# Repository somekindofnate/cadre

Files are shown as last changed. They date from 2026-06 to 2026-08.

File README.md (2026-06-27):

```
 ░▒▓██████▓▒░ ░▒▓██████▓▒░░▒▓███████▓▒░░▒▓███████▓▒░░▒▓████████▓▒░ 
░▒▓█▓▒░░▒▓█▓▒░▒▓█▓▒░░▒▓█▓▒░▒▓█▓▒░░▒▓█▓▒░▒▓█▓▒░░▒▓█▓▒░▒▓█▓▒░        
░▒▓█▓▒░      ░▒▓█▓▒░░▒▓█▓▒░▒▓█▓▒░░▒▓█▓▒░▒▓█▓▒░░▒▓█▓▒░▒▓█▓▒░        
░▒▓█▓▒░      ░▒▓████████▓▒░▒▓█▓▒░░▒▓█▓▒░▒▓███████▓▒░░▒▓██████▓▒░   
░▒▓█▓▒░      ░▒▓█▓▒░░▒▓█▓▒░▒▓█▓▒░░▒▓█▓▒░▒▓█▓▒░░▒▓█▓▒░▒▓█▓▒░        
░▒▓█▓▒░░▒▓█▓▒░▒▓█▓▒░░▒▓█▓▒░▒▓█▓▒░░▒▓█▓▒░▒▓█▓▒░░▒▓█▓▒░▒▓█▓▒░        
 ░▒▓██████▓▒░░▒▓█▓▒░░▒▓█▓▒░▒▓███████▓▒░░▒▓█▓▒░░▒▓█▓▒░▒▓████████▓▒░ 

Civilian-Available Drone REcon
```

### Disclaimer
The following program is intended for research purposes **only**. The situations described are fictional in nature and only used as examples. As the MIT license states:

> THE SOFTWARE IS PROVIDED “AS IS”, WITHOUT WARRANTY OF ANY KIND, EXPRESS OR IMPLIED, INCLUDING BUT NOT LIMITED TO THE WARRANTIES OF MERCHANTABILITY, FITNESS FOR A PARTICULAR PURPOSE AND NONINFRINGEMENT. IN NO EVENT SHALL THE AUTHORS OR COPYRIGHT HOLDERS BE LIABLE FOR ANY CLAIM, DAMAGES OR OTHER LIABILITY, WHETHER IN AN ACTION OF CONTRACT, TORT OR OTHERWISE, ARISING FROM, OUT OF OR IN CONNECTION WITH THE SOFTWARE OR THE USE OR OTHER DEALINGS IN THE SOFTWARE.

**Using this software in an unlicensed, unauthorized way can put you in prison. Don't do it.**

# Rationale
As of 2026, ongoing conflicts have showed that when the lack of military hardware is available, state and nonstate actors will turn to civilian, off-the-shelf (COTS) hardware. The Myanmar Civil War \[1\], Russo-Ukrainian conflict, and -- to a lesser degree -- Syrian Civil War \[3\] and outspringing conflicts have all used commercially available drones for mission-built purposes.

Because necessity is the mother of invention, both military-industrial grade and battlefield made countermeasures have been used successfully to stop drones. [The Ukranian Chuyka](https://www.blue-bird.tech/en/products/chuyka-3-0/) is a valuable piece of tech for front line troops, allowing them to eavesdrop on unecrypted, analog video of loitering drones. However, it's a piece of tech that's almost $2,000 here in the United States. There are other drone detection hardware devices of varying quality [littered across eBay](https://www.ebay.com/itm/376574536302). Inspired by Colonel Panic's [Drone Mesh Mapper](https://github.com/colonelpanichacks/drone-mesh-mapper) and [DroneAware.io](https://droneaware.io/), this project is an exploration of what technologies could be used in a cheap, open, and commercially-available way to detect a hypothetical drone incursion.

The scope of this research is limited to the 2.4GHZ and 5.8GHZ bands that some commercially-available drones use for controls, phone-home, or analog/digital video signals. This is not intended for fiber optic, special-frequency, industrial, or other drone types. There is no warranty provided and the authors of this project shall not be held liable for any part in the use of this project.

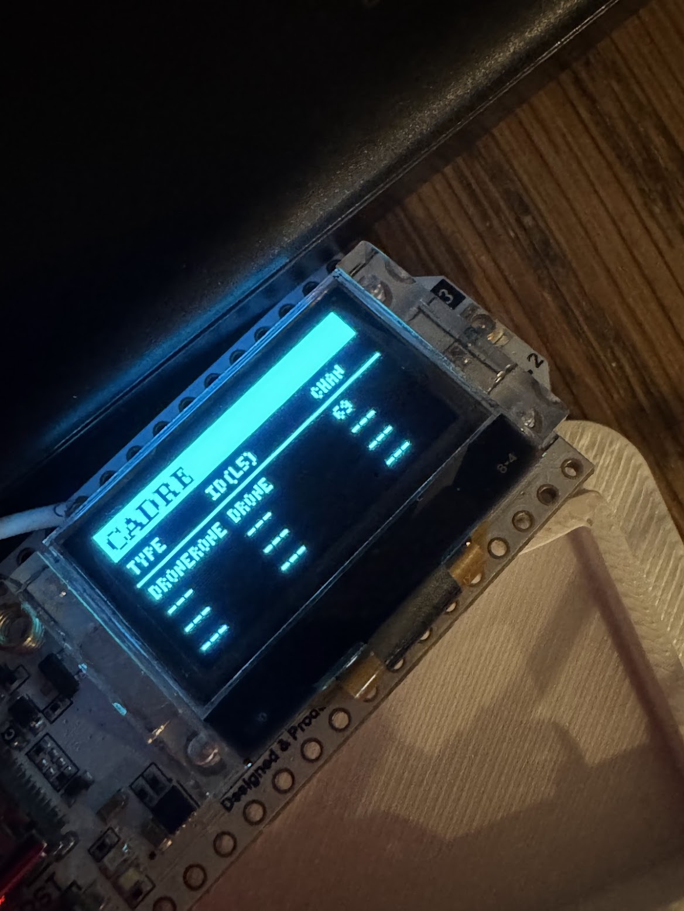
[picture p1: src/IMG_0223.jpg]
CADRE homescreen


# Layout
This project is laid out as 3 distinct folders: Hardware, firmware, and docs.

## Hardware
Here you'll find the .STL for printing the sled to affix the boards to. This will also contain links to the hardware needed for this project.

## Firmware
This folder will contain the firmware for the hub and each spoke. This project assumes you have had some experience with microcontrollers, but a platformio.ini is included for each of the ESP32 boards.

## Docs
This will eventually contain a step-by-step guide for how to wire the project, but for now, it's empty. This project accepts pull requests, but documentation needs to be written for humans, by humans.

# Bill of Materials
| **Part** | **Cost** | **Source** |
| --- | --- | --- |
| ESP32S3 (2.4ghz node) | $7.99 | [Seeed Studio](https://www.seeedstudio.com/Seeed-Studio-XIAO-ESP32S3-Plus-p-6361.html) |
| BW16 IPEX (5.8ghz node) | $10.77 | [AliExpress](https://www.aliexpress.us/item/3256810605716193.html) |
| Heltec V3 (hub) | $25.00 | [Amazon](https://www.amazon.com/AYWHP-Development-Meshtastic-Bluetooth-863-928MHz/dp/B0DMN28TRW/ref=sr_1_3) |
| USB-A to 3x USB-C splitter | $7.98 | [Amazon](https://www.amazon.com/dp/B09WRBK8HD) |
| 5.8ghz antenna | $18.47 | [Amazon](https://www.amazon.com/dp/B0GL7QSNNK) |
| USB Power bank | $16.99 | [Amazon](https://www.amazon.com/dp/B0FGDCY95C) |

**Considerations**

- The listed antenna is purpose-built for drone application, but any antenna for 2.4ghz and 5.8ghz will suffice.

- For power banks, the listed USB power bank is sufficient for 12+ hours of use, but any USB power bank will work.

- If you choose to forego the 3-pronged USB and wire the boards a different way, they will need a shared ground wire.

# Wiring
Because each board is only responsible for transmitting when it finds a specific piece of data, the wiring is extremely pared back.

| **From ESP32S3** | **To HeltecV3** |
| --- | --- |
| D7 (GPIO44) | Pin 7 (GPIO42) |

| **From BW16** | **To HeltecV3** |
| --- | --- |
| PA7 (LOG_TX) | Pin 8 (GPIO41) |

---
1. ["An Inside View into Drone Warfare in Myanmar."](https://www.geopoliticalmonitor.com/an-inside-view-into-drone-warfare-in-myanmar/) February 21, 2025.
2. ["Eyewitness to war: Ukraine’s DIY drones defy Russian jamming."](https://www.gisreportsonline.com/r/ukraine-diy-drones/) May 4, 2026.
3. ["The Drones of Hayat Tahrir al-Sham: The Development and Use of UAS in Syria."](https://gnet-research.org/2024/12/20/the-drones-of-hayat-tahrir-al-sham-the-development-and-use-of-uas-in-syria/) December 20, 2024.

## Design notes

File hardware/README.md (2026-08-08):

```
 ░▒▓██████▓▒░ ░▒▓██████▓▒░░▒▓███████▓▒░░▒▓███████▓▒░░▒▓████████▓▒░ 
░▒▓█▓▒░░▒▓█▓▒░▒▓█▓▒░░▒▓█▓▒░▒▓█▓▒░░▒▓█▓▒░▒▓█▓▒░░▒▓█▓▒░▒▓█▓▒░        
░▒▓█▓▒░      ░▒▓█▓▒░░▒▓█▓▒░▒▓█▓▒░░▒▓█▓▒░▒▓█▓▒░░▒▓█▓▒░▒▓█▓▒░        
░▒▓█▓▒░      ░▒▓████████▓▒░▒▓█▓▒░░▒▓█▓▒░▒▓███████▓▒░░▒▓██████▓▒░   
░▒▓█▓▒░      ░▒▓█▓▒░░▒▓█▓▒░▒▓█▓▒░░▒▓█▓▒░▒▓█▓▒░░▒▓█▓▒░▒▓█▓▒░        
░▒▓█▓▒░░▒▓█▓▒░▒▓█▓▒░░▒▓█▓▒░▒▓█▓▒░░▒▓█▓▒░▒▓█▓▒░░▒▓█▓▒░▒▓█▓▒░        
 ░▒▓██████▓▒░░▒▓█▓▒░░▒▓█▓▒░▒▓███████▓▒░░▒▓█▓▒░░▒▓█▓▒░▒▓████████▓▒░ 

Civilian-Available Drone REcon
```

# Enclosure
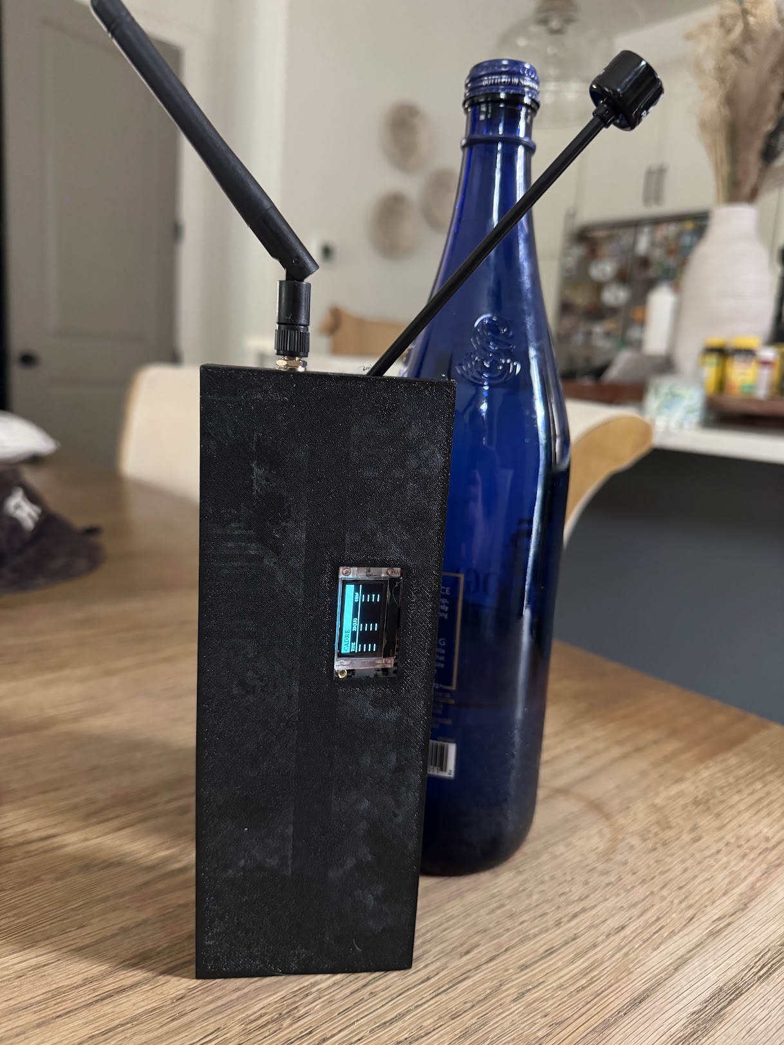
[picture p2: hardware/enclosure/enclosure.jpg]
CADRE enclosure


With the 8/26 update, I've added an enclosure that can be printed and snapped together to hold the pieces. I used double sided adhesive tape to tape the chips face-down (so that the bottom of the chip can vent out of the back of the case).

It's just a big empty case, but maybe some of y'all are better at running wires than me.

# Bill of Materials

| **Part** | **Cost** | **Source** |
| --- | --- | ---|
| ESP32S3 (2.4ghz node) | $7.99 | [Seeed Studio](https://www.seeedstudio.com/Seeed-Studio-XIAO-ESP32S3-Plus-p-6361.html) |
| BW16 IPEX (5.8ghz node) | $10.77 | [AliExpress](https://www.aliexpress.us/item/3256810605716193.html) |
| Heltec V3 (hub) | $25.00 | [Amazon](https://www.amazon.com/AYWHP-Development-Meshtastic-Bluetooth-863-928MHz/dp/B0DMN28TRW/ref=sr_1_3) |
| USB-A to 3x USB-C splitter | $7.98 | [Amazon](https://www.amazon.com/dp/B09WRBK8HD) |
| 5.8ghz antenna | $18.47 | [Amazon](https://www.amazon.com/dp/B0GL7QSNNK) |
| USB Power bank | $16.99 | [Amazon](https://www.amazon.com/dp/B0FGDCY95C) |

Antennas, power banks, and USB splitters are all optional if you have you own or want to power the boards a different way. All boards need to share a common ground, and a single USB cable was a way to simplify that.

# Wiring

Because each board is only responsible for transmitting when it finds a specific piece of data, the wiring is extremely pared back.

| **From ESP32S3** | **To HeltecV3** |
| --- | --- |
| D7 (GPIO44) | Pin 7 (GPIO42) |

| **From BW16** | **To HeltecV3** |
| --- | --- |
| PA7 (LOG_TX) | Pin 8 (GPIO41) |

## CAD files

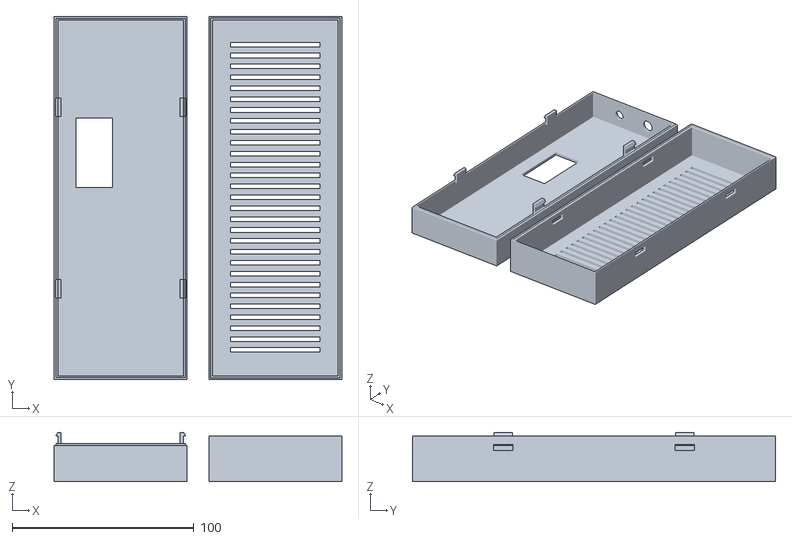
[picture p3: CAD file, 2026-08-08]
hardware/enclosure/enclosure.stl
158.2 x 199.7 x 27.1

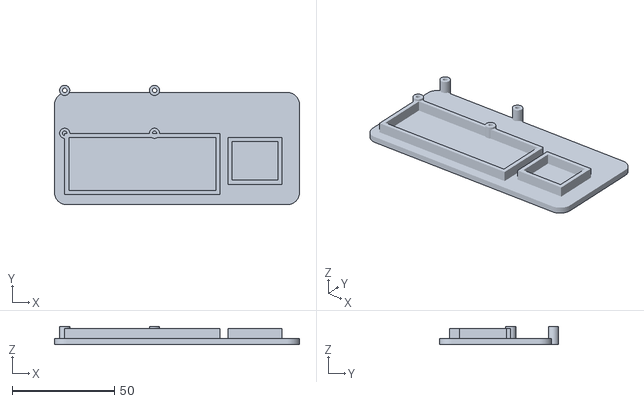
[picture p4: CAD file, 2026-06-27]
hardware/sled/sled_skeleton.stl
120.0 x 58.5 x 9.00

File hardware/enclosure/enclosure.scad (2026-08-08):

/*
  Handheld Drone Detector Enclosure - Extended (+2")
  Hardware: ESP32S2, Heltec (w/ Screen), BW16, USB Power Bank
  Mechanism: 4x Cantilever Snap Joints
*/

$fn = 60; // Smoothness for circular cutouts

// --- Printer Tolerances & Settings ---
wall = 2.0;       // Standard 2mm shell thickness
tol = 0.15;       // Clearance tolerance for the alignment lip

// --- Snap Joint Parameters ---
snap_w = 10.0;      // Width of the snap arm
snap_t = 1.8;       // Thickness of the cantilever arm
snap_l = 7.0;       // Length of the snap extending past the rim
snap_h = 1.2;       // Hook protrusion depth

// --- Internal Dimensions (mm) ---
// Battery: 136.9 x 67.1 x 15 (Updated to exact 15mm thickness)
bat_w = 67.1;
bat_h = 136.9;
bat_d = 15.0;

usb_clearance = 58.8;       // 8mm original + 50.8mm (2 inches) for cable routing
int_w = bat_w + 2;          // 69.1mm wide internal cavity
int_h = bat_h + usb_clearance; // 195.7mm high total cavity
front_depth = 18.0;         // Depth for boards (Accounts for BW16 header pins)

// back_depth is bat_d + 8 to raise bottom walls & clasp receivers 
back_depth = bat_d + 8;     

// --- External Dimensions ---
ext_w = int_w + (wall * 2);
ext_h = int_h + (wall * 2);
ext_d = front_depth + back_depth + (wall * 2);

// --- Component Coordinates ---
// Screen rotated vertically, widened by ~6.35mm (0.25"), plus an extra 2mm in height
screen_w = 20;     // Original short edge
screen_h = 38.35;  // Original long edge (30) + 6.35mm (0.25") + 2.0mm

// Anchored from the top down, left justified with a buffer for the board
screen_x = wall + 10; // Left-justified 10mm from internal wall
screen_y = ext_h - 75; 

sma_dia = 6.5;        // ESP32S2 Antenna Port
foxeer_dia = 8.0;     // BW16 Antenna Port

// --- View Selector ---
// 0 = Exploded View, 1 = Front Face Only, 2 = Back Cover Only
part = 0; 

if (part == 0) {
    front_half();
    translate([ext_w + 12, 0, 0]) back_half();
} else if (part == 1) {
    front_half();
} else if (part == 2) {
    back_half();
}

// ==========================================
//                 MODULES
// ==========================================

module hook_left() {
    // Main cantilever arm
    cube([snap_t, snap_w, snap_l]);
    // The wedge ramp and catch (facing outward to the left)
    translate([-snap_h, 0, snap_l - 2])
        hull() {
            cube([0.1, snap_w, 0.1]);                       // Bottom catching ledge
            translate([snap_h, 0, 2]) cube([0.1, snap_w, 0.1]); // Top tip (flush with arm)
            translate([snap_h, 0, 0]) cube([0.1, snap_w, 0.1]); // Base of the wedge
        }
}

module hook_right() {
    // Main cantilever arm
    translate([-snap_t, 0, 0]) cube([snap_t, snap_w, snap_l]);
    // The wedge ramp and catch (facing outward to the right)
    translate([0, 0, snap_l - 2])
        hull() {
            translate([snap_h, 0, 0]) cube([0.1, snap_w, 0.1]); // Bottom catching ledge
            translate([0, 0, 2]) cube([0.1, snap_w, 0.1]);      // Top tip (flush with arm)
            cube([0.1, snap_w, 0.1]);                           // Base of the wedge
        }
}

module front_half() {
    union() {
        difference() {
            // Main Outer Block
            cube([ext_w, ext_h, front_depth + wall]);
            
            // Hollow Internal Cavity
            translate([wall, wall, wall])
                cube([int_w, int_h, front_depth + 1]);
                
            // Heltec Screen Cutout (Vertical & Left-Justified)
            translate([screen_x, screen_y - (screen_h/2), -1])
                cube([screen_w, screen_h, wall + 2]);
                
            // Top Face Antenna Ports
            translate([ext_w/3, ext_h + 1, wall + (front_depth/2)])
                rotate([90, 0, 0])
                cylinder(d=sma_dia, h=wall+2);
                
            translate([ext_w*2/3, ext_h + 1, wall + (front_depth/2)])
                rotate([90, 0, 0])
                cylinder(d=foxeer_dia, h=wall+2);
        }
        
        // 1mm Alignment Lip (Keeps the two halves from shearing sideways)
        translate([wall/2, wall/2, front_depth + wall])
            difference() {
                cube([ext_w - wall, ext_h - wall, 1]); 
                translate([wall/2, wall/2, -1])
                    cube([ext_w - wall*2, ext_h - wall*2, 3]);
            }
            
        // 4x Cantilever Snaps
        for (y = [ext_h*0.25, ext_h*0.75]) {
            translate([wall, y - snap_w/2, front_depth + wall])
                hook_left();
            translate([ext_w - wall, y - snap_w/2, front_depth + wall])
                hook_right();
        }
    }
}

module back_half() {
    difference() {
        // Main Outer Block
        cube([ext_w, ext_h, back_depth + wall]);
        
        // Hollow Battery Cavity
        translate([wall, wall, wall])
            cube([int_w, int_h, back_depth + 1]);
            
        // Female Alignment Groove
        translate([wall/2 - tol, wall/2 - tol, back_depth + wall - 1])
            difference() {
                cube([ext_w - wall + (tol*2), ext_h - wall + (tol*2), 2]);
                translate([wall/2 + (tol*2), wall/2 + (tol*2), -1])
                    cube([ext_w - wall*2 - (tol*4), ext_h - wall*2 - (tol*4), 4]);
            }
            
        // Snap Receiver Windows (Cut fully through the outer shell)
        for (y = [ext_h*0.25, ext_h*0.75]) {
            // Left window
            translate([-1, y - (snap_w+1)/2, back_depth + wall - snap_l - 1])
                cube([wall + 2, snap_w + 1, 3.5]);
            // Right window
            translate([ext_w - wall - 1, y - (snap_w+1)/2, back_depth + wall - snap_l - 1])
                cube([wall + 2, snap_w + 1, 3.5]);
        }
            
        // Horizontal Vents (Full length of the back)
        // Spaced every 6mm, starting from 15mm up to near the top
        for (i = [0 : floor((ext_h - 30) / 6)]) {
            translate([wall + 10, 15 + (i * 6), -1])
                cube([ext_w - 20 - (wall*2), 2.5, wall + 2]);
        }
    }
}

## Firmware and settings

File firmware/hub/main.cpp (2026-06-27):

#include <Arduino.h>
#include <U8g2lib.h>
#include <Wire.h>

// Buzzer
const int buzzerPin = 8;

// ==========================================
// HELTEC V3 OLED CONFIGURATION
// ==========================================
U8G2_SSD1306_128X64_NONAME_F_HW_I2C u8g2(U8G2_R0, /* reset=*/ 21, /* clock=*/ 18, /* data=*/ 17);

// ==========================================
// THREAT DATABASE
// ==========================================
const int MAX_TARGETS = 4; 
const unsigned long TARGET_TIMEOUT = 10000; // Increased to 10s for stability

struct DroneTarget {
  String brand;
  String macShort;
  String channel;
  unsigned long lastSeen;
  bool active;
};

DroneTarget targets[MAX_TARGETS];

String shortenMac(String fullMac) {
  return (fullMac.length() >= 5) ? fullMac.substring(fullMac.length() - 5) : fullMac;
}

bool processThreatData(String data, unsigned long currentMillis) {
  data.trim();
  int firstComma = data.indexOf(',');
  int secondComma = data.lastIndexOf(',');
  
  if (firstComma == -1 || secondComma == -1 || firstComma == secondComma) return false;

  String brand = data.substring(0, firstComma);
  String fullMac = data.substring(firstComma + 1, secondComma);
  String channel = data.substring(secondComma + 1);
  String macShort = shortenMac(fullMac);

  // LOG FOR DEBUGGING
  Serial.println("INCOMING: " + brand + " | MAC: " + macShort);

  // Update existing
  for (int i = 0; i < MAX_TARGETS; i++) {
    if (targets[i].active && targets[i].macShort == macShort) {
      targets[i].lastSeen = currentMillis;
      targets[i].channel = channel;
      return true;
    }
  }

  // Add new
  for (int i = 0; i < MAX_TARGETS; i++) {
    if (!targets[i].active) {
      targets[i].brand = brand;
      targets[i].macShort = macShort;
      targets[i].channel = channel;
      targets[i].lastSeen = currentMillis;
      targets[i].active = true;
      Serial.println("DEBUG: New Target stored in slot " + String(i));
      return true;
    }
  }
  return false;
}

void drawMatrix() {
  u8g2.clearBuffer();
  u8g2.setDrawColor(1);
  u8g2.drawBox(0, 0, 128, 13);
  u8g2.setDrawColor(0);
  u8g2.setFont(u8g2_font_ncenB08_tr); 
  u8g2.drawStr(2, 11, "CADRE");
  u8g2.setDrawColor(1);
  u8g2.setFont(u8g2_font_4x6_tr); 
  u8g2.drawStr(2, 22, "TYPE");
  u8g2.drawStr(42, 22, "ID(L5)");
  u8g2.drawStr(98, 22, "CHAN");
  u8g2.drawLine(0, 25, 128, 25); 

  int yPos = 34;
  for (int i = 0; i < MAX_TARGETS; i++) {
    if (targets[i].active) {
      u8g2.drawStr(2, yPos, targets[i].brand.c_str());
      u8g2.drawStr(42, yPos, targets[i].macShort.c_str());
      u8g2.drawStr(98, yPos, targets[i].channel.c_str());
    } else {
      u8g2.drawStr(2, yPos, "---");
      u8g2.drawStr(42, yPos, "---");
      u8g2.drawStr(98, yPos, "---");
    }
    yPos += 9; 
  }
  u8g2.sendBuffer();

  tone(buzzerPin, 1000);
  delay(250);
  noTone(buzzerPin);

  tone(buzzerPin, 1000);
  delay(250);
  noTone(buzzerPin);
}

void setup() {
  Serial.begin(115200);   
  
  pinMode(21, OUTPUT);
  digitalWrite(21, LOW); delay(100);
  digitalWrite(21, HIGH); delay(100);
  
  // Initialize nodes: Alpha (5GHz) on 41, Bravo (2.4GHz) on 42
  Serial1.begin(4800, SERIAL_8N1, 41, -1); // Alpha (5GHz)
  Serial2.begin(4800, SERIAL_8N1, 42, -1); // Bravo (2.4GHz)

  // 1. HARDWARE POWER-ON (Vext Control)
  pinMode(36, OUTPUT);
  digitalWrite(36, LOW); 
  delay(100);

  // 2. I2C PIN INITIALIZATION
  Wire.begin(17, 18); 

  // 3. START DISPLAY
  u8g2.begin();

  // 4. MESHTASTIC LUMINANCE INJECTION
  u8g2.setContrast(255);        
  u8g2.sendF("ca", 0xD9, 0xF1); 
  u8g2.sendF("ca", 0xDB, 0x40); 
  
  for (int i = 0; i < MAX_TARGETS; i++) targets[i].active = false;
  drawMatrix();
  Serial.println("HUB READY. LISTENING ON GPIO 41 AND 42...");
}

void loop() {
  unsigned long currentMillis = millis();
  bool matrixChanged = false;

  // Process Alpha (5GHz) - Pin 41
  if (Serial1.available() > 0) {
    if (Serial1.read() == '$') {
      String data = Serial1.readStringUntil('\n');
      if (processThreatData(data, currentMillis)) {
        matrixChanged = true;
        Serial.println("DEBUG: Alpha Update");
      }
    }
  }

  // Process Bravo (2.4GHz) - Pin 42
  if (Serial2.available() > 0) {
    if (Serial2.read() == '$') {
      String data = Serial2.readStringUntil('\n');
      if (processThreatData(data, currentMillis)) {
        matrixChanged = true;
        Serial.println("DEBUG: Bravo Update");
      }
    }
  }

  // Aging cleanup
  for (int i = 0; i < MAX_TARGETS; i++) {
    if (targets[i].active && (currentMillis - targets[i].lastSeen > TARGET_TIMEOUT)) {
      targets[i].active = false;
      matrixChanged = true; 
    }
  }

  if (matrixChanged) {
    drawMatrix();
  }
}

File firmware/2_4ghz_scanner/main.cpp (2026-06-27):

#include <Arduino.h>
#include <WiFi.h>
#include <esp_wifi.h>

// ==========================================
// TARGET OUI DATA
// ==========================================
struct DroneOUI {
  uint8_t oui[3];
  const char* brand;
};

const DroneOUI KNOWN_DRONES[] = {
  // --- DJI (Massive Allocation Block) ---
  {{0x04, 0xA8, 0x5A}, "DJI"},
  {{0x0C, 0x9A, 0xE6}, "DJI"},
  {{0x34, 0xD2, 0x62}, "DJI"},
  {{0x48, 0x1C, 0xB9}, "DJI"},
  {{0x4C, 0x43, 0xF6}, "DJI"},
  {{0x58, 0xB8, 0x58}, "DJI"},
  {{0x60, 0x60, 0x1F}, "DJI"},
  {{0x88, 0x29, 0x85}, "DJI"},
  {{0x8C, 0x58, 0x23}, "DJI"},
  {{0xE4, 0x7A, 0x2C}, "DJI"},
  {{0xDC, 0x0E, 0xA1}, "DJI (Compal)"},
  
  // --- Autel Robotics ---
  {{0xEC, 0x5B, 0xCD}, "Autel"},
  
  // --- Parrot ---
  {{0x90, 0x03, 0xB7}, "Parrot"},
  {{0x00, 0x26, 0x7E}, "Parrot"},
  {{0x00, 0x12, 0x1C}, "Parrot"},
  {{0xA0, 0x14, 0x3D}, "Parrot"},
  
  // --- Skydio ---
  {{0x38, 0x1D, 0x14}, "Skydio"}, 

  // --- Common FPV / Cheap Toy Drones ---
  {{0x4C, 0x0F, 0xC7}, "Sky Rider"},
  {{0x08, 0xEA, 0x40}, "Generic FPV"}, 
  {{0xE0, 0xB9, 0x4D}, "Generic FPV"}  
};
const int NUM_OUIs = sizeof(KNOWN_DRONES) / sizeof(KNOWN_DRONES[0]);

// ==========================================
// UART CONFIGURATION
// ==========================================
HardwareSerial CADRE_Serial(1); // Use Serial1
#define TX_PIN D7               // Ensure this matches your wiring

void sniffCallback(void* buf, wifi_promiscuous_pkt_type_t type) {
  wifi_promiscuous_pkt_t* pkt = (wifi_promiscuous_pkt_t*)buf;
  uint8_t* frame = pkt->payload;
  
  // 802.11 Management frames (Beacons) are usually at offset 0 in the payload
  // MAC Source is at offset 10 of the frame
  uint8_t* src = frame + 10;

  for (int i = 0; i < NUM_OUIs; i++) {
    if (src[0] == KNOWN_DRONES[i].oui[0] && 
        src[1] == KNOWN_DRONES[i].oui[1] && 
        src[2] == KNOWN_DRONES[i].oui[2]) {
      
      char macStr[18];
      snprintf(macStr, sizeof(macStr), "%02X:%02X:%02X:%02X:%02X:%02X", 
               src[0], src[1], src[2], src[3], src[4], src[5]);

      // Hub Parsing Format: $Brand,MAC,Channel
      CADRE_Serial.print("$");
      CADRE_Serial.print(KNOWN_DRONES[i].brand);
      CADRE_Serial.print(",");
      CADRE_Serial.print(macStr); // Can be shortened in Hub
      CADRE_Serial.print(",CH");
      CADRE_Serial.println(WiFi.channel());
      
      // Debounce: Prevent the Hub from locking up
      delay(300); 
      break; 
    }
  }
}

void setup() {
  Serial.begin(115200);
  CADRE_Serial.begin(4800, SERIAL_8N1, -1, TX_PIN);

  // Initialize Wi-Fi
  WiFi.mode(WIFI_MODE_STA);
  WiFi.disconnect();

  // Use the native ESP-IDF function
  esp_wifi_set_promiscuous(true);
  esp_wifi_set_promiscuous_rx_cb(&sniffCallback);

  wifi_promiscuous_filter_t filter = {
    .filter_mask = WIFI_PROMIS_FILTER_MASK_MGMT
  };
  esp_wifi_set_promiscuous_filter(&filter);
  
  Serial.println("XIAO 2.4GHz Node Active.");
}

void loop() {
  // Hopping 1, 6, 11 (Standard Drone Control Channels)
  static int channels[] = {1, 6, 11};
  static int i = 0;
  
  esp_wifi_set_channel(channels[i], WIFI_SECOND_CHAN_NONE);
  i = (i + 1) % 3;
  
  delay(1000); // Dwell time per channel
}

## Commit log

2026-06-27 initial commit of CADRE.
    [sled_skeleton.stl]
2026-08-08 Include 3d printable enclosure in the hardware dir
    [enclosure.scad, enclosure.stl]
